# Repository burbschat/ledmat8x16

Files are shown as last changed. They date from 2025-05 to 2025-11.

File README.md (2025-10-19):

# *LTP-12188M-08* Based Two Color 8x16 LEDs in 8x8 Slots LED Matrix Display Module

## Motivation
Found a place that sold their dead stock of *LTP-12188M-08* modules for
extremely cheap and bought a whole bunch.
To drive those I would like to have a minimal and cheap solution which is also
modular, meaning I can build an (for any practical purposes) arbitrarily sized
display by just assembling identical modules (and perhaps a few cables etc.).

## Pictures
### Renders
Had some fun with [this incredible
tool](https://github.com/30350n/pcb2blender). Shown renders are of the first
version of the single tile driver board.
There is a newer revision with extra features for mouting as well as a *blade*
version where 8 modules are combined into one long board, as that is a much
more reasonable solution for large displays.

| Front | Back | Oblique
| --- | --- | --- |
| Front Render | Front Render | Oblique Render |

### Prototype
Testing three prototype modules driven by a Raspberry Pi Pico (which is
debugged from a second Pico via SWD).
The colors do look much more vibrant in person. Also, the apparent differences
in brightness are an artifact of the way this picture was captured.

3 Module Test Setup with Pico 

A second test now using the controller and row connect boards for a double row
display. Again, the colors look much better in person than on this picture.
This can now display much larger frames as well as animations (cycling through
a given number of frames in a buffer on the pico). For faster data transfer a
serial interface over USB is used (previously UART through the debug probe was
used, which is much slower).
A debug probe is still attached for, well, debugging. But the device now can be
used without it.

double row test 

## Parts
* *LTP-12188M-08* (8x8 two-color (red/green) LED dot matrix)
* *TLC59283* (16 channel constant current LED driver with pre-charge FET)
    * Seems to be cheapest LED driver available
    * No dimming supported but perhaps possible by updating the frames at a high enough rate
    * Can be daisy chained
    * Up to 32MHz operation advertised
        * One frame is 8 rows x 16 bits = 128 transfers. At 32MHz one transfer
        takes 3.125e-08s so 4e-6s per frame per tile. For 60 tiles thats
        240e-6s for the whole panel. If we want 60 frames per second
        (16.666e-3s per frame), we can sub-divide each frame into 69 sections
        for which a pixel can be either on or off. Thus a 69 level brightness
        adjustment may be possible.
* *DMP31D7LDW-13* (dual p-channel enhancement mode MOSFET)
    * Seems to be the cheapest on DigiKey with ~500ma sustained current
    * Should switch fast enough
        * NTZD3152P may be a faster alternative, but tolerates less peak
        current (sustained currents is similar though)
* Board connectors
    * DigiKey
        * *Ph2ra-16-ua*
            * cheapest on DigiKey
            * mating connector from same manufacturer seems to be rs2br-16-g? but
            this is not readily available and of odd shape...
        * *pptc082ljbn-rc*
            * Cheapest mating connector on DigiKey
        * *Consider buying those from lcsc where they should be much cheaper*
    * LCSC
        * *2541WR-2x08P*
            * Extremely cheap
        * *PM254-2-08-W-8.5*
            * Mating part from same manufacturer: PZ254-2-08-W-8.5

### Notes
* There seems to be no cheap LED driver which supports row *and* column driving
    * IS31FL3731 seems to be pretty capable. Costs a little more but is still
    affordable. However, choosing the simpler part will surely teach one more
    things than just buying the solution.

#### LED Currents
* Use 5V supply
    * The TLC59283 are constant current and support up to 10V
        * The constant-current value of all 16 channels is set by a single external resistor
    * 3.3V may also work, but may be insufficient for some chips, so use 5V
* Peak forward current is 60mA/90mA (green/red)
    * 16 columns (8 red 8 green) on one row so peak current of 1200 mA per row
* Average current is 25mA (same for both colors)
    * Total of 400mA average current per row (if all 16 channels are on)
    * A 500mA sustained/1.2A peak driver should be sufficient
    * In actual operation the rows are multiplexed so actually only about an
    eight of the average current is expected. So actually 400mA sustained
    current per tile if all LEDs are on.
    * Eventually set the current limit at the TLC59283 to around 25mA
        * 2k resistor should give 26.5mA, which is alright
* Want row drivers separately for each tile to avoid driver current scaling
with number of tiles
    * Make sure that connections between tiles support high enough currents
* Consider [MOSFET arrays](https://www.digikey.com/en/products/filter/transistors/fets-mosfets/fet-mosfet-arrays/289)
as we need 8 of them per tile
    * Need P-channel to drive by setting gate voltage low (below source voltage)
    * Maybe not too long rise/fall times 
    * DMP31D7LDW-13 seems fine (20JPY at 200 pieces, doesn't seem to get much cheaper on digikey)
        * There are many SOT-363 options so if this one does not work, one can
        probably find a pin compatible alterative
    * [Search on digikey](https://www.digikey.jp/en/products/filter/transistors/fets-mosfets/fet-mosfet-arrays/289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)

#### Clock
The clock will have to arrive at each TLC59283 before the output of the
previous one had a chance to change. According to the data sheet, the delay
until SOUT changes is normally around 11ns. As we are only concerned about
adjacent modules in close proximity, the clock propagation delay should be well
below 10ns.
A possible concern mentioned [here](https://www.eevblog.com/forum/projects/shift-register-delay-tlc59283/msg5714097/#msg5714097)
is that the clock signal integrity may be degraded due to large capacitance if
we fan it out too far. To solve this we may employ a buffer, this however would
mean we need either a very fast buffer to not skew the clock relative to the
data signal too much, or also have to buffer the data signal at the same time.
Buffering two signals should be doable.
This is probably not an issue, but technically if the buffers are to slow, this
could limit the rate at which we can operate the panel (i.e. clock in data).
As, if it works, no buffers should be the easier solution, for now I'll try
without. If required, we may try to add clock line terminations to avoid
ringing.

## Mechanical Design
* Board interconnects using horizontal pin headers on the back of the board (tile is on the front)
    * 8 pins seem to fit just right, so two rows with 8 pins each seems to be a good choice
    * These also will provide mechanical support within each row
* Consider some sort of locating feature to use to locate modules in maybe a
3d-printed back plane or with small clips to be inserted between modules (**TODO**) 
    * Could shave off the corners and have short square (45 deg. rotated) posts on the back plane
    * High symmetry is probably a good thing so locating features on maybe only
    top/bottom may not be as useful as the shaved off corners
    * To assemble multiple rows such a locating feature would be required
    * For a large display with many rows and columns a backplane is probably mandatory
    
## Heat Dissipation
Found that when I run a fully lit frame (all 16 LEDs enabled while multiplexing
the rows) the whole module gets quite hot. Not entirely sure what produces the
heat. If it is the TLC59283, one could simply remove the solder mask on the
back side of the board which is a ground plane to which the ground pad on the
TLC59283 is connected to and place some sort of heat sink there.
This is of course the reason why the TLC59283 is placed under the LED matrix
module on the front and not at the back of the board and not simply attributed
to be not checking the orientation of the modules footprint before doing the
tedious routing which I do not want to do twice.
Will have to further check what is the source of the heat. However, as long as
the display is not constantly fully illuminated, it does not appear to get
excessively hot.

## Driving the Modules
I use an Raspberry Pi Pico (2 to be exact) to the modules. The serial interface
for the TLC59283 is implemented using a PIO state machine (with DMA) which can
clock out serial data independent of the processor cores and thus is a very
performant solution. Switching between the rows is done by the processor which
also feeds data from a global frame buffer to the DMA (which feeds it to the
PIO state machine).
Other microcontrollers will probably also work. Not sure how one would handle
the serial communication though. AT a slower rate one can perhaps just bit bang
using GPIO. Didn't try.
The code I use on the Pico is available in a separate repository [here](https://github.com/burbschat/ledmat8x16pico/).

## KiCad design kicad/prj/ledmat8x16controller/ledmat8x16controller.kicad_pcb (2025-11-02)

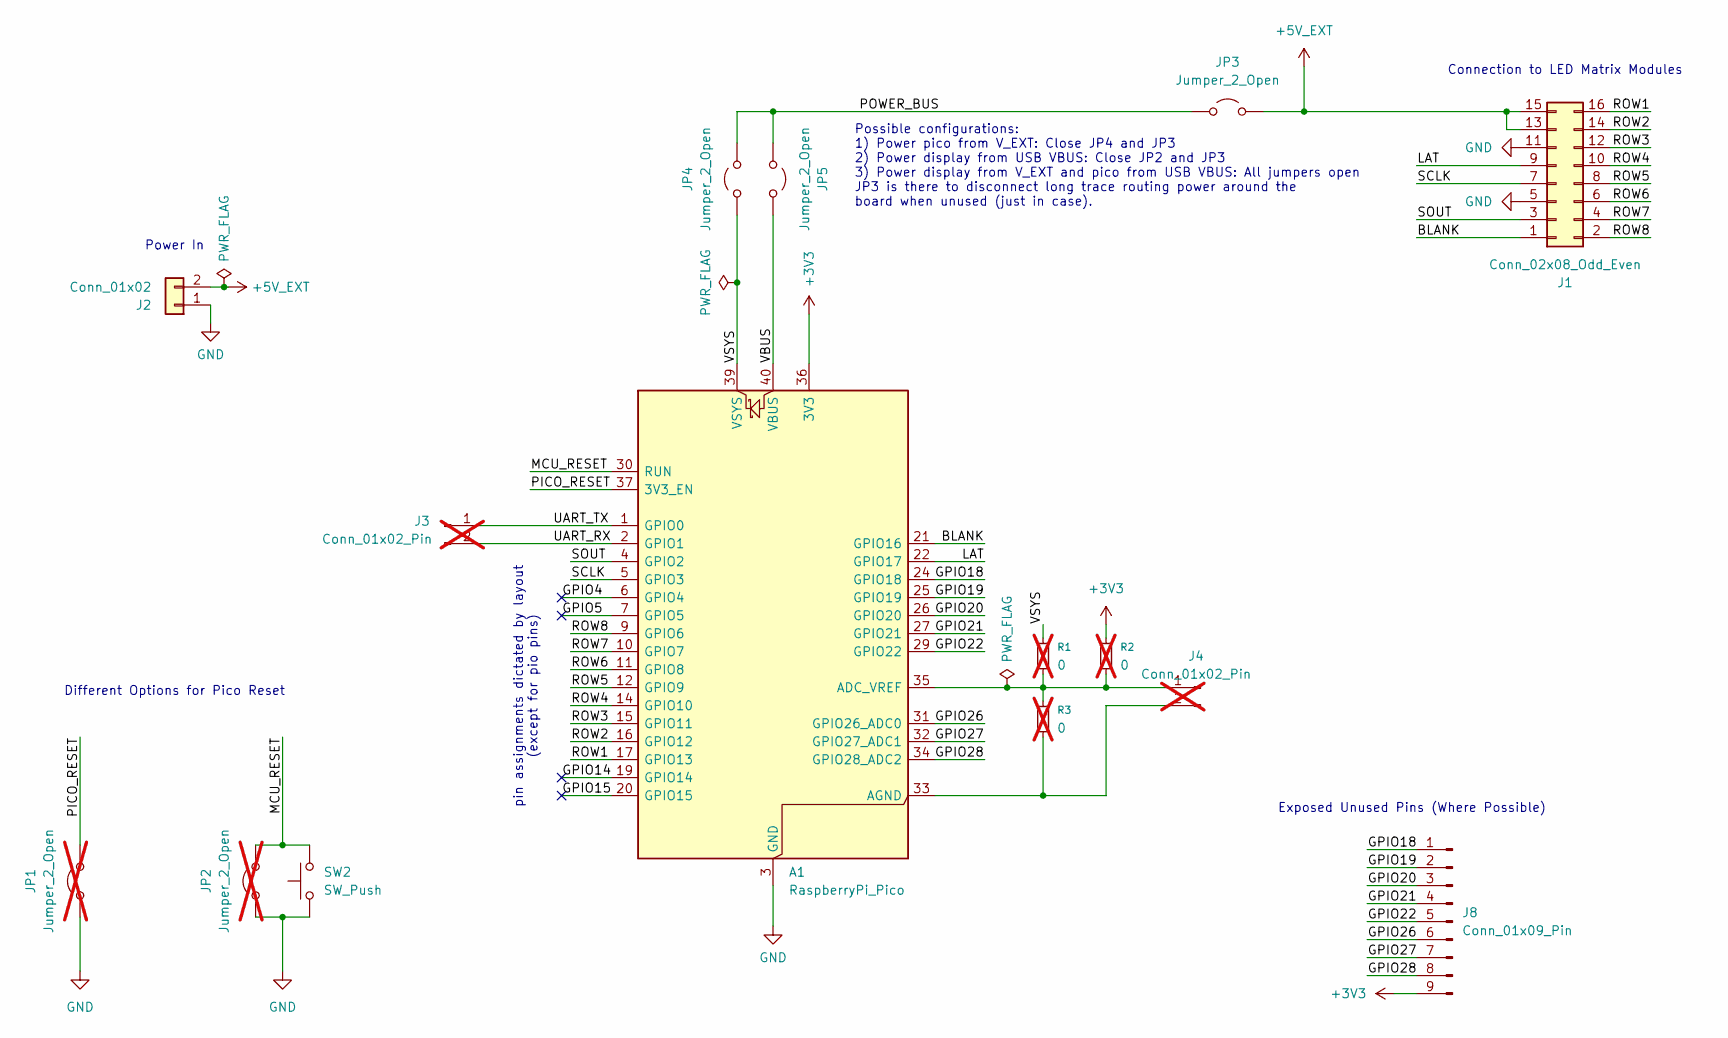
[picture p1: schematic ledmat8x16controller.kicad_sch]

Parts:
A1: RaspberryPi_Pico; RaspberryPi_Pico_Common_ProbablySocketed
J1: Conn_02x08_Odd_Even; PinSocket_2x08_P2.54mm_Horizontal
J2: Conn_01x02; TerminalBlock_Phoenix_PT-1,5-2-3.5-H_1x02_P3.50mm_Horizontal
J3, J4: Conn_01x02_Pin; PinHeader_1x02_P2.54mm_Vertical; not fitted
J8: Conn_01x09_Pin; PinHeader_1x09_P2.54mm_Vertical
JP1, JP2: Jumper_2_Open; TestPoint_2Pads_Pitch2.54mm_Drill0.8mm; not fitted
JP3, JP4, JP5: Jumper_2_Open; SolderJumper-2_P1.3mm_Open_RoundedPad1.0x1.5mm
R1, R2, R3: 0; R_0603_1608Metric_Pad0.98x0.95mm_HandSolder; not fitted
SW2: SW_Push; SW_SPST_SKQG_WithStem

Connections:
+3V3: A1.36 (3V3), J8.9, R2.1
+5V_EXT: J1.13, J1.15, J2.2, JP3.2 (B)
/BLANK: A1.21 (GPIO16), J1.1
/GPIO4: A1.6 (GPIO4)
/GPIO4_1: A1.6 (GPIO4)
/GPIO5: A1.7 (GPIO5)
/GPIO5_1: A1.7 (GPIO5)
/GPIO14: A1.19 (GPIO14)
/GPIO14_1: A1.19 (GPIO14)
/GPIO15: A1.20 (GPIO15)
/GPIO15_1: A1.20 (GPIO15)
/GPIO18: A1.24 (GPIO18), J8.1
/GPIO19: A1.25 (GPIO19), J8.2
/GPIO20: A1.26 (GPIO20), J8.3
/GPIO21: A1.27 (GPIO21), J8.4
/GPIO22: A1.29 (GPIO22), J8.5
/GPIO26: A1.31 (GPIO26_ADC0), J8.6
/GPIO27: A1.32 (GPIO27_ADC1), J8.7
/GPIO28: A1.34 (GPIO28_ADC2), J8.8
/LAT: A1.22 (GPIO17), J1.9
/MCU_RESET: A1.30 (RUN), JP2.2 (B), SW2.2
/PICO_RESET: A1.37 (3V3_EN), JP1.2 (B)
/POWER_BUS: JP3.1 (A), JP4.2 (B), JP5.2 (B)
/ROW1: A1.17 (GPIO13), J1.16
/ROW2: A1.16 (GPIO12), J1.14
/ROW3: A1.15 (GPIO11), J1.12
/ROW4: A1.14 (GPIO10), J1.10
/ROW5: A1.12 (GPIO9), J1.8
/ROW6: A1.11 (GPIO8), J1.6
/ROW7: A1.10 (GPIO7), J1.4
/ROW8: A1.9 (GPIO6), J1.2
/SCLK: A1.5 (GPIO3), J1.7
/SOUT: A1.4 (GPIO2), J1.3
/UART_RX: A1.2 (GPIO1), J3.2
/UART_TX: A1.1 (GPIO0), J3.1
/VBUS: A1.40 (VBUS), JP5.1 (A)
/VSYS: A1.39 (VSYS), JP4.1 (A), R1.1
GND: A1.3 (GND), A1.8 (GND), A1.13 (GND), A1.18 (GND), A1.23 (GND), A1.28 (GND), A1.38 (GND), J1.5, J1.11, J2.1, JP1.1 (A), JP2.1 (A), SW2.1
unnamed: A1.35 (ADC_VREF), J4.1, R1.2, R2.2, R3.1
unnamed: A1.33 (AGND), J4.2, R3.2

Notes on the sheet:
Exposed Unused Pins (Where Possible)
Connection to LED Matrix Modules
Possible configurations: 1) Power pico from V_EXT: Close JP4 and JP3 2) Power display from USB VBUS: Close JP2 and JP3 3) Power display from V_EXT and pico from USB VBUS: All jumpers open JP3 is there to disconnect long trace routing power around the board when unused (just in case).
pin assignments dictated by layout (except for pio pins)
Power In
Different Options for Pico Reset

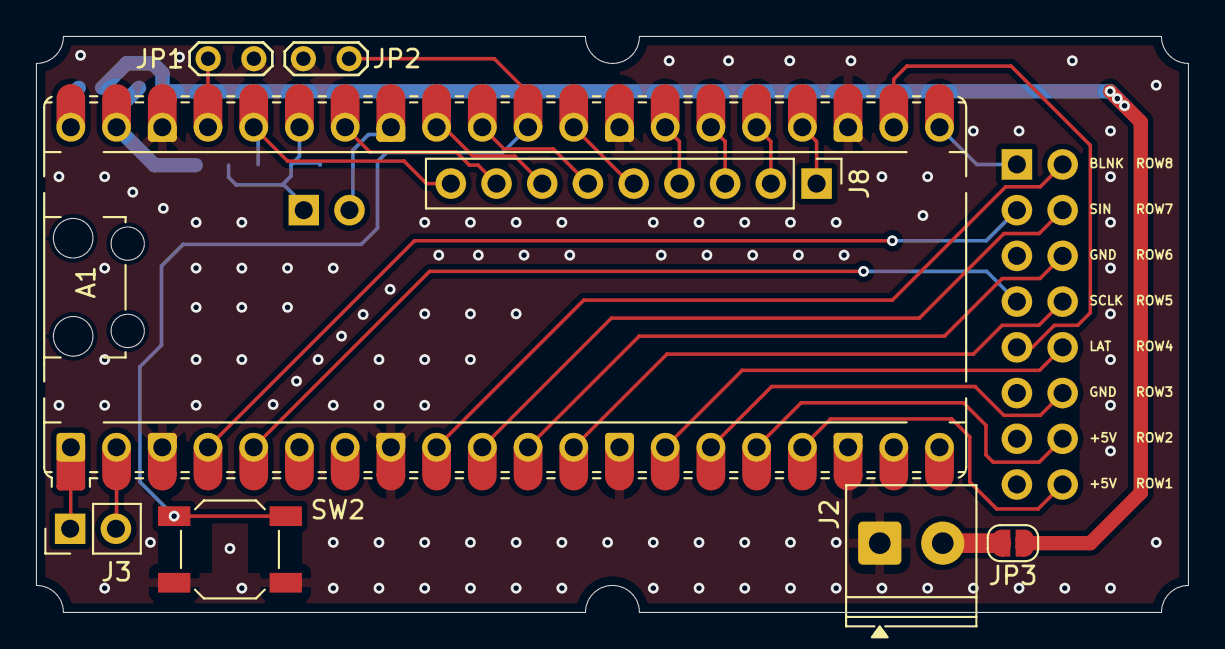
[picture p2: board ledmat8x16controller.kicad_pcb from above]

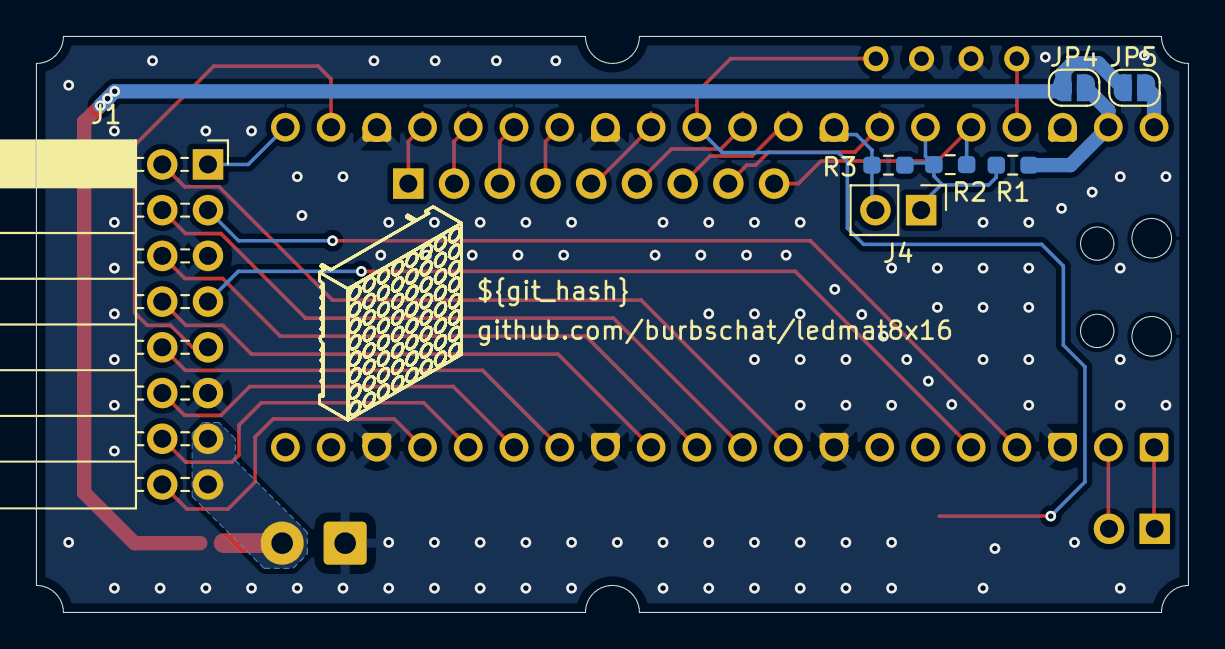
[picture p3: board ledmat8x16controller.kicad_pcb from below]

Board: 2 copper layers, 64.0 x 32.0 mm, 15 parts (7 on the bottom side), 32 nets.

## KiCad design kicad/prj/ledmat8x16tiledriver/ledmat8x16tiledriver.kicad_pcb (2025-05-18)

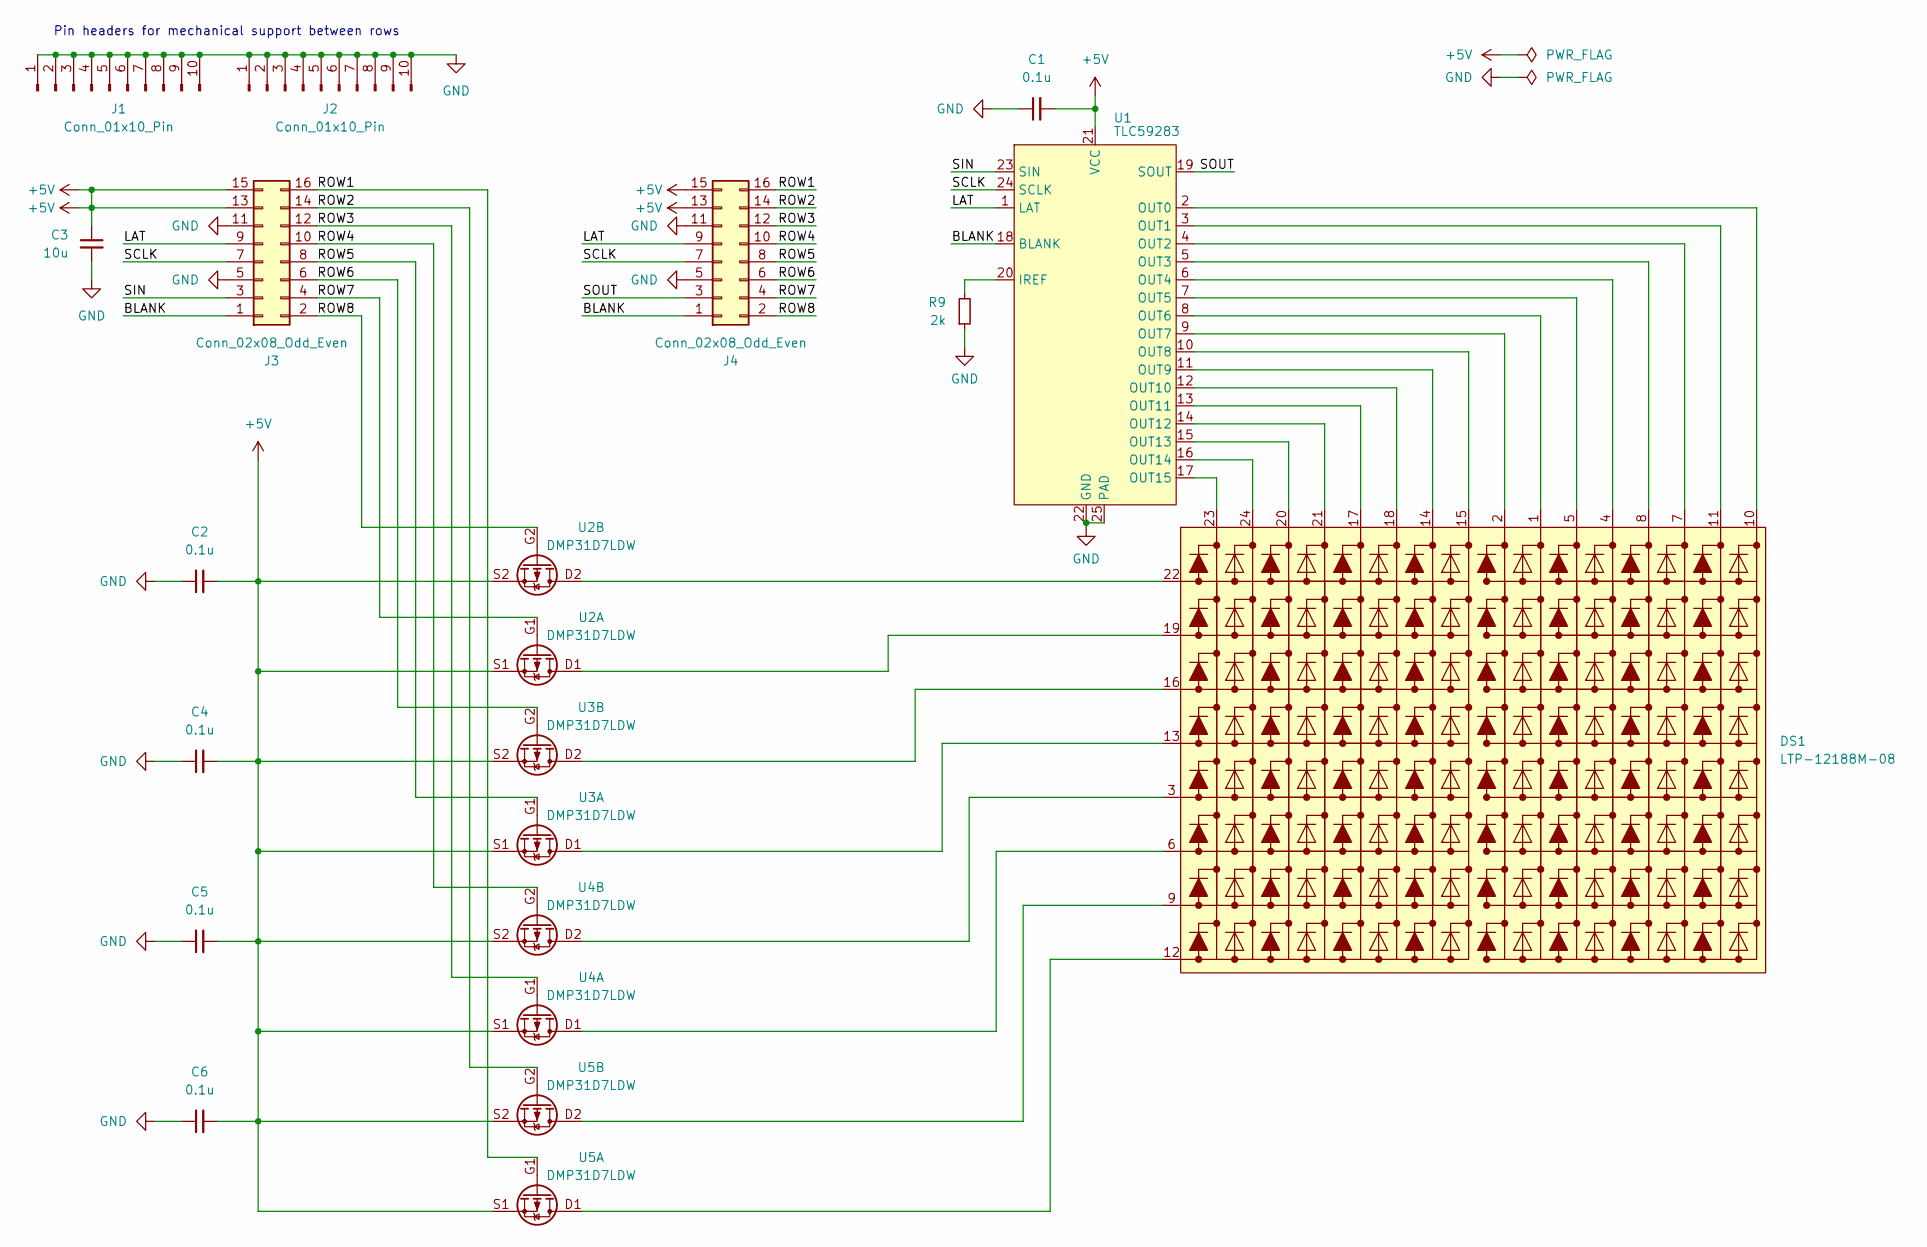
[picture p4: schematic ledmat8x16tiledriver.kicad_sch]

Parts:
C1, C2, C4, C5, C6: 0.1u; C_0603_1608Metric_Pad1.08x0.95mm_HandSolder
C3: 10u; C_0805_2012Metric_Pad1.18x1.45mm_HandSolder
DS1: LTP-12188M-08
J1, J2: Conn_01x10_Pin; PinHeader_1x10_P2.54mm_Vertical
J3: Conn_02x08_Odd_Even; PinHeader_2x08_P2.54mm_Horizontal
J4: Conn_02x08_Odd_Even; PinSocket_2x08_P2.54mm_Horizontal
R9: 2k; R_0603_1608Metric_Pad0.98x0.95mm_HandSolder
U1: TLC59283; Texas_RGE0024C_VQFN-24-1EP_4x4mm_P0.5mm_EP2.1x2.1mm
U2, U3, U4, U5: DMP31D7LDW; SOT-363_SC-70-6

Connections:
+5V: C1.2, C2.2, C3.1, C4.2, C5.2, C6.2, J3.13, J3.15, J4.13, J4.15, U1.21 (VCC), U2.S1, U2.S2, U3.S1, U3.S2, U4.S1, U4.S2, U5.S1, U5.S2
/BLANK: J3.1, J4.1, U1.18 (BLANK)
/LAT: J3.9, J4.9, U1.1 (LAT)
/ROW1: J3.16, J4.16, U5.G1
/ROW2: J3.14, J4.14, U5.G2
/ROW3: J3.12, J4.12, U4.G1
/ROW4: J3.10, J4.10, U4.G2
/ROW5: J3.8, J4.8, U3.G1
/ROW6: J3.6, J4.6, U3.G2
/ROW7: J3.4, J4.4, U2.G1
/ROW8: J3.2, J4.2, U2.G2
/SCLK: J3.7, J4.7, U1.24 (SCLK)
/SIN: J3.3, U1.23 (SIN)
/SOUT: J4.3, U1.19 (SOUT)
GND: C1.1, C2.1, C3.2, C4.1, C5.1, C6.1, J1.1, J1.2, J1.3, J1.4, J1.5, J1.6, J1.7, J1.8, J1.9, J1.10, J2.1, J2.2, J2.3, J2.4, J2.5, J2.6, J2.7, J2.8, J2.9, J2.10, J3.5, J3.11, J4.5, J4.11, R9.1, U1.22 (GND), U1.25 (PAD)
unnamed: DS1.3, U4.D2
unnamed: DS1.6, U4.D1
unnamed: DS1.9, U5.D2
unnamed: DS1.12, U5.D1
unnamed: DS1.13, U3.D1
unnamed: DS1.16, U3.D2
unnamed: DS1.19, U2.D1
unnamed: DS1.22, U2.D2
unnamed: R9.2, U1.20 (IREF)
unnamed: DS1.10, U1.2 (OUT0)
unnamed: DS1.11, U1.3 (OUT1)
unnamed: DS1.7, U1.4 (OUT2)
unnamed: DS1.8, U1.5 (OUT3)
unnamed: DS1.4, U1.6 (OUT4)
unnamed: DS1.5, U1.7 (OUT5)
unnamed: DS1.1, U1.8 (OUT6)
unnamed: DS1.2, U1.9 (OUT7)
unnamed: DS1.15, U1.10 (OUT8)
unnamed: DS1.14, U1.11 (OUT9)
unnamed: DS1.18, U1.12 (OUT10)
unnamed: DS1.17, U1.13 (OUT11)
unnamed: DS1.21, U1.14 (OUT12)
unnamed: DS1.20, U1.15 (OUT13)
unnamed: DS1.24, U1.16 (OUT14)
unnamed: DS1.23, U1.17 (OUT15)

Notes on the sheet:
Pin headers for mechanical support between rows

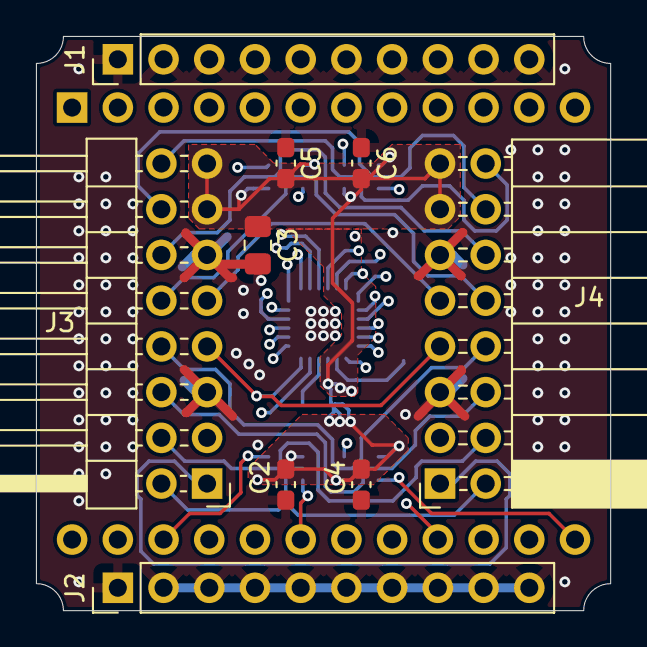
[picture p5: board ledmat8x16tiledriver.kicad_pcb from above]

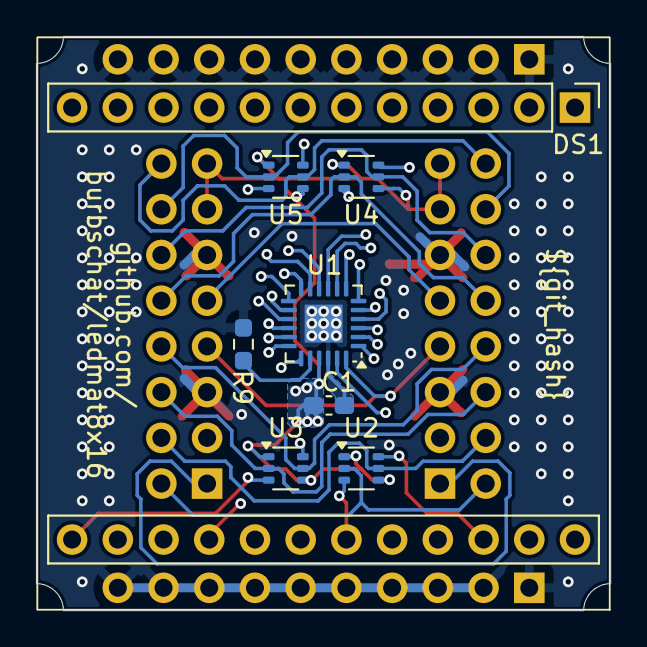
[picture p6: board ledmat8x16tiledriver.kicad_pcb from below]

Board: 4 copper layers, 31.9 x 31.9 mm, 17 parts (8 on the bottom side), 40 nets.

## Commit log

2025-03-23 initial notes and collection of datasheets
    [ledmat8x16tiledriver.kicad_pcb, ledmat8x16tiledriver.kicad_sch]
2025-03-24 draw basic schematic
    some footprint assignment is still todo
    [ledmat8x16tiledriver.kicad_pcb, ledmat8x16tiledriver.kicad_sch]
2025-03-24 create/assign all footprints
    [ledmat8x16tiledriver.kicad_sch]
2025-03-27 finish layout (witch a catch)
    I put the led matrix footprint on the wrong side of the board...
    This was fixed by moving the pin headers which however now results in
    the controller IC being under the led matrix module. Not what I wanted
    but not easy to fix. I wanted to use headers to mount the module anyways
    to there should be no interference. Try to use some short female pin
    headers (which apparently is a thing).
    [ledmat8x16tiledriver.kicad_pcb, ledmat8x16tiledriver.kicad_sch]
2025-04-13 re-route traces close to clock trace
    Clock appeared to couple into the closeby traces
    [ledmat8x16tiledriver.kicad_pcb]
2025-04-13 attempt to increase space between data and blank traces
    also observed coupling of data into the blank line.
    [ledmat8x16tiledriver.kicad_pcb]
2025-05-03 Fix empty value field for TLC59283
    [ledmat8x16tiledriver.kicad_sch]
2025-05-03 Add 3d model for led matrix module
    [ledmat8x16tiledriver.kicad_pcb]
2025-05-03 Add 3d model for socketed version of the led matrix module
    [ledmat8x16tiledriver.kicad_pcb]
2025-05-03 Add some renders of the PCB
2025-05-13 Fix wrong footprint type for led matrix module
2025-05-13 Update footprints in layout (including the led matrix module one)
    [ledmat8x16tiledriver.kicad_pcb]
2025-05-13 Cut little arcs into the corners for mounting modules with maybe M3 screws
    Or perhaps standoffs?
    [ledmat8x16tiledriver.kicad_pcb]
2025-05-13 Fix led modules footprint througholes out of alignment by 0.01mm
    Of course this does not really matter, but it bugs me.
2025-05-13 Add some holes for headers near the top/bottom edge
    Perhaps this can be used as a different way of mounting. Not sure, I'll
    have to try. Unfortunately the board dimensions did not allow for the
    spacing to be a multiple of 2.54mm. But positioning is such that between
    adjacent rows the headers should be exactly 2.54mm apart.
    [ledmat8x16tiledriver.kicad_pcb, ledmat8x16tiledriver.kicad_sch]
2025-05-13 Update small resistor symbol to match library
    [ledmat8x16tiledriver.kicad_sch]
2025-05-16 Slight adjustments to zone fill and ground plane
    [ledmat8x16tiledriver.kicad_pcb]
2025-05-16 Update footprint to newer version (with smaller courtyard)
    [ledmat8x16tiledriver.kicad_pcb]
2025-05-16 Add repo url and git hash to silkscreen
    For traceability, but also just becasue it's possible.
    Substitution of git hash is done by kibot.
    [ledmat8x16tiledriver.kicad_pcb]
2025-05-18 Add files for a simple row interconnect board
    [ledmat8x16rowconnect.kicad_pcb, ledmat8x16rowconnect.kicad_sch]
2025-05-18 Indicate some of the important dimensions on the user drawings layer
    [ledmat8x16tiledriver.kicad_pcb]
2025-05-18 Add dimensions to interconnect board, fix silkscreen
    [ledmat8x16rowconnect.kicad_pcb]
2025-05-18 Fix slight asymetry in zone fill
    [ledmat8x16rowconnect.kicad_pcb]
2025-05-23 Add rasperry pi pico library repo as submodule
2025-05-23 Add footprint and symbol library tables to interconnect project
2025-05-31 Throw together a pico breakout board
    Not very sophisticated at all, but probably will do the job (which is to
    avoid having to connect all the lines separately using jumper wires).
    [ledmat8x16controller.kicad_pcb, ledmat8x16controller.kicad_sch]
2025-08-03 Combine 8 modules into a single "blade" pcb
    This allows for fewer connectors with large displays.
    A "blade" is "hackable" in the sense of cutting it up into separate
    modules which should still function on their own.
    [ledmat8x16tiledriver_blade.kicad_sch, ledmat8x16tiledriver_single.kicad_sch]
2025-08-03 Resize controller board to 32mm outline
    [ledmat8x16controller.kicad_pcb]
2025-08-03 Resize row-connect board to 32mm outline
    [ledmat8x16rowconnect.kicad_pcb]
2025-08-04 Add missing git hash silkscreen to controller board
    [ledmat8x16controller.kicad_pcb]
2025-11-02 Rework the controller (pico carrier) board
    Previous version was thrown together in a short time as I was ordering
    boards anyways and wanted to test the concept for a pico carrier thing.
    [ledmat8x16controller.kicad_pcb, ledmat8x16controller.kicad_sch]
2025-11-02 Additions to silkscreen
    [ledmat8x16controller.kicad_pcb]
2025-11-02 Add svgs used on silkscreen
2025-11-02 Change all led module modules to socketed 3d model on blade board
2025-11-02 Change headers for mounting to dnp on blade pcb
    [ledmat8x16tiledriver_single.kicad_sch]
2025-11-02 Fix socketed module 3d model socket pin color
    (and some broken links)
